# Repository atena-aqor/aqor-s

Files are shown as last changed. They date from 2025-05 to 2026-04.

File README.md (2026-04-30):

# Architecture du projet AQOR
## Présentation du projet
Le projet AQOR de mesure de la qualité de l'air et du bruit est organisé autour de capteurs fonctionnant sur batterie communiquant en protocole LORA avec une passerelle LORA-->Wifi permettant d'envoyer les mesures à un centre de collecte et de diffusion. Le projet comprend donc des aspects de fabircation du matériel et de développement du logiciel associé. Ces différents points sont abordés sur dépôt

### Architecture matérielle

 Le logiciel du projet AQOR a été développé en 3 parties distinctes qui reflètent l’architecture matérielle montrée ici:
 
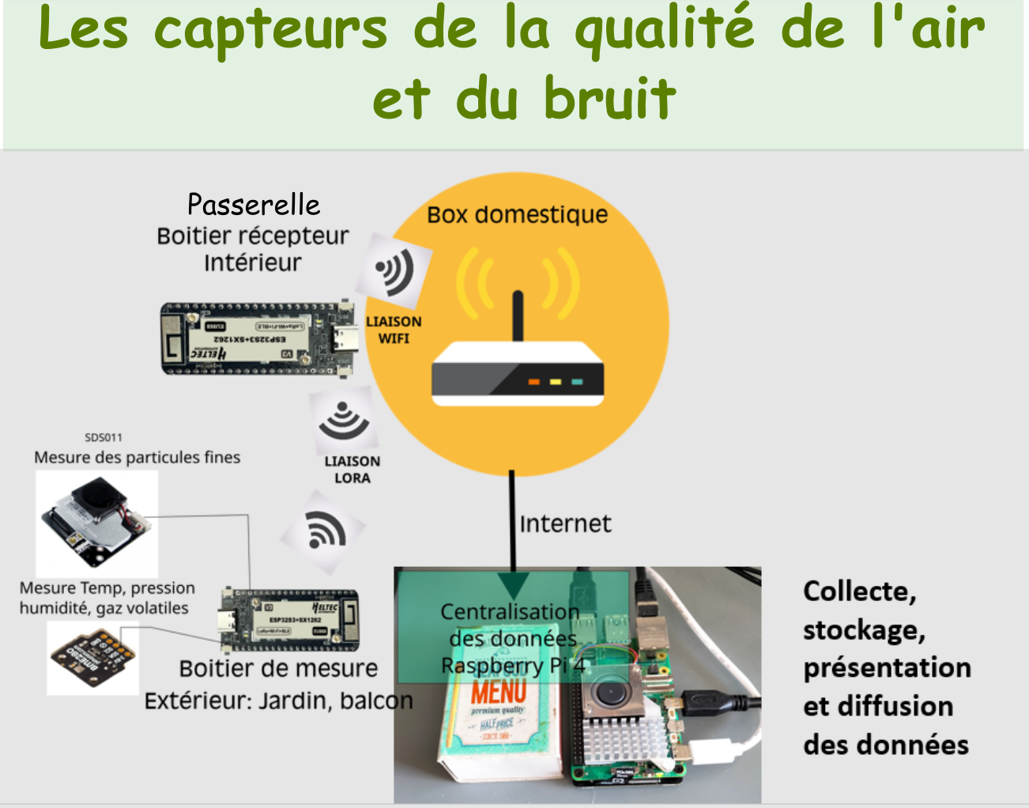
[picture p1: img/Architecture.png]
Architecture


#### Cartes électroniques pour le capteur 
L'électronique du capteur extérieur repose sur 3 cartes électronique dont les PCB réalisés avec KiCAD sont donnés dans les répertoires 
- pour la carte processeur: [Carte_Processeur](https://github.com/atena-aqor/aqor-s/tree/main/AQOR_Carte_Capteurs)
- pour la carte supportant les capteurs BME80 et INMP441 [Carte BME680/INMP441](https://github.com/atena-aqor/aqor-s/tree/main/AQOR_Carte_processeur)
Les cartes ont été développées avec le logiciel libre KiCAD en version 7.0

#### Boîtiers à imprimer
Les fichiers .STL pour l'impression 3D des boitiers sont donnés dans le répertoire: [Boitiers](https://github.com/atena-aqor/aqor-s/tree/main/AQOR%20STL)

### Architecture logicielle

Elle comprend:
- Un programme implanté dans le boîtier Emetteur qui fonctionne sur batterie
- Un programme implanté dans le boîtier Passerelle qui est connecté en WiFi à la box internet de l’hébergeur 
- Un logiciel Open Source de collecte et de diffusion des données implanté sur un micro-ordinateur Raspberry Pi5 fonctionnant sous linux UBUNTU. 

Les codes sources des programmes d'**émission** et de **passerelle** sont décrits dans les répertoires correspondants. Les fichiers Readme.md de chaque répertoire permettent de connaître le rôle de chaque fichier 

### Compilation des fichiers arduino 

Les fichiers proposés sont compilables sur la version de l'IDE Arduino 1.8.19 dont il faut choisir les préférences indiquées dans la figure suivante 

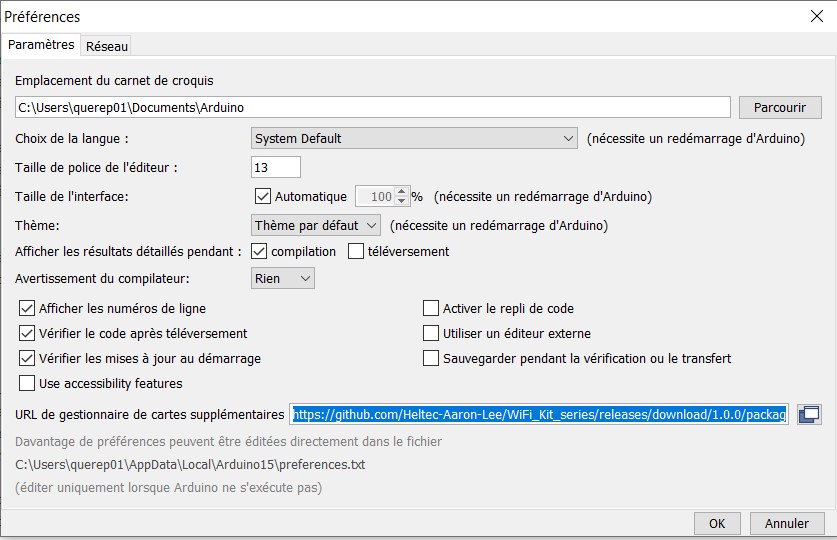
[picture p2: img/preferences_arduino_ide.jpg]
preferences_Arduino


le lien exact surligné en bleu  est [https://github.com/Heltec-Aaron-Lee/WiFi_Kit_series/releases/download/1.0.0/package_heltec_esp32_index.json](https://github.com/Heltec-Aaron-Lee/WiFi_Kit_series/releases/download/1.0.0/package_heltec_esp32_index.json)

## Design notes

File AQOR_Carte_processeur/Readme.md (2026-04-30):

# Fichiers de fabrication et de conception de la carte Processeurs
## Fichiers de fabrication
Dans ce répertoire on trouve les fichiers de fabrication qui peuvent être utilisés pour la réalisation des PCB de la carte processeur utilisée. Cette carte comporte le cablage du processeur et les connecteurs vers les différents éléments du capteur
L'aspect physique de la carte est donnée à la figure  ci-dessous 

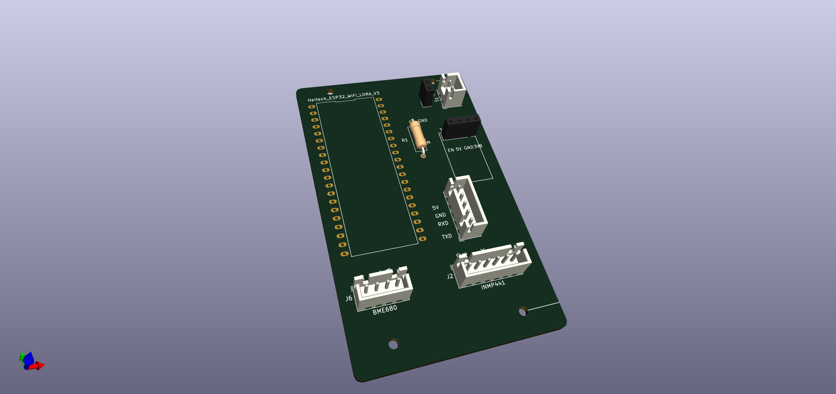
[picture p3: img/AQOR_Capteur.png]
CarteCapteur


et le schéma Kicad du PCB est donné ci-dessous

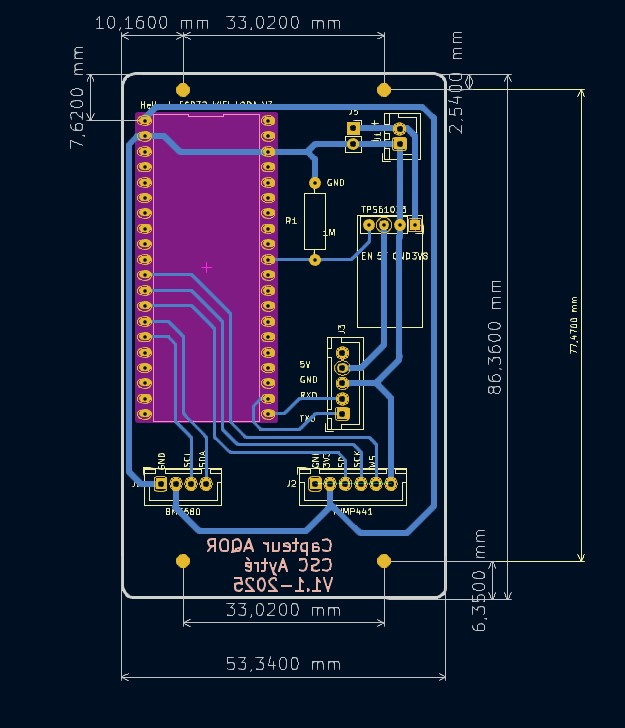
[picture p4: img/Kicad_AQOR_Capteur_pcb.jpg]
Kicad_PCB_carte_capteur


## Fichiers de conception 
La conception a été réalisée avec KICAD 7.0 [https://www.kicad.org/](https://www.kicad.org/)
Les fichiers de conception sont donnés dans le fichier [Kicad_AQOR_Capteur.zip](https://github.com/atena-aqor/aqor-s/blob/main/AQOR_Carte_processeur/Kicad_AQOR_Capteur.zip)

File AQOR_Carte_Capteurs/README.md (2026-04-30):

# Fichiers de fabrication et de conception de la carte Capteurs 
## Fichiers de fabrication
Dans ce répertoire on trouve les fichiers de fabrication qui peuvent être utilisés pour la réalisation des PCB de la carte processeur utilisée. Cette carte comporte le cablage du processeur et les connecteurs vers les différents éléments du capteur
L'aspect physique de la carte est donnée à la figure  ci-dessous 

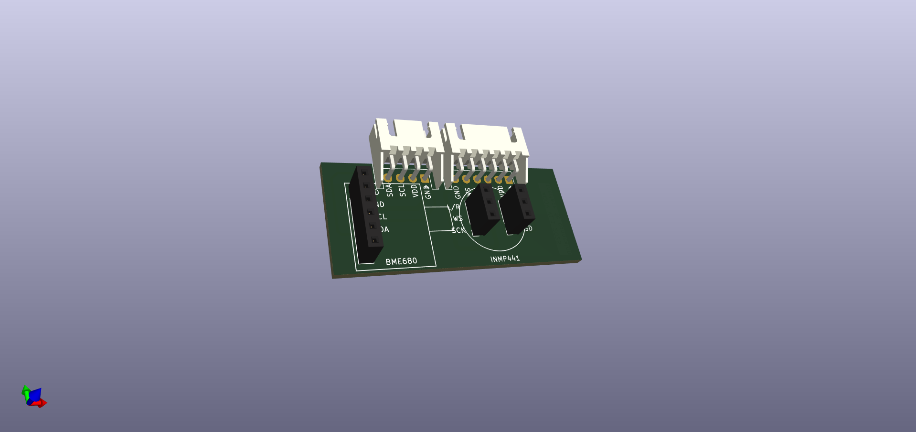
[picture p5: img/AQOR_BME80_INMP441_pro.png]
CarteCapteur


et le schéma Kicad du PCB est donné ci-dessous

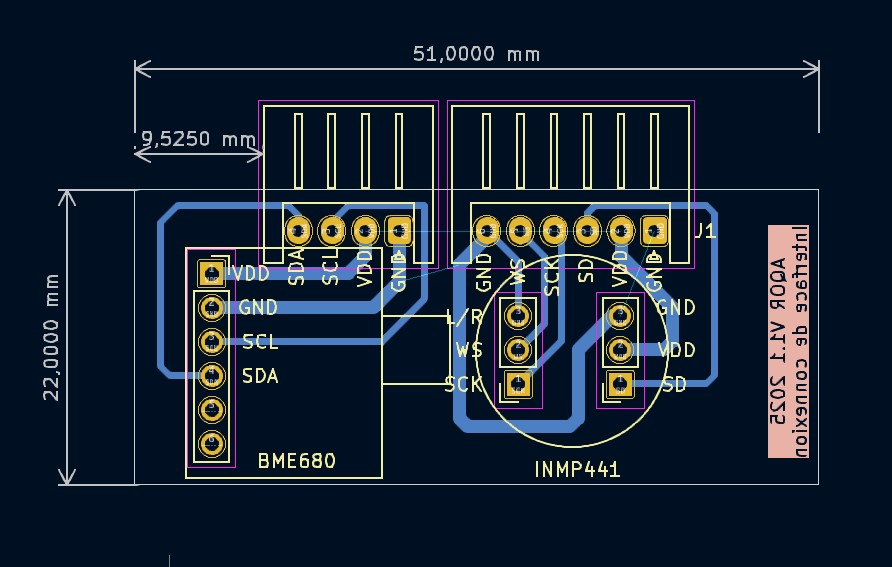
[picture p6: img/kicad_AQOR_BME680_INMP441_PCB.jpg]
Kicad_PCB_carte_capteur


## Fichiers de conception 
La conception a été réalisée avec KICAD 7.0 [https://www.kicad.org/](https://www.kicad.org/)
Les fichiers de conception sont donnés dans le fichier [Kicad_AQOR_BME80_INMP441_pro.zip](https://github.com/atena-aqor/aqor-s/blob/main/AQOR_Carte_Capteurs/Kicad_AQOR_BME80_INMP441_pro.zip)

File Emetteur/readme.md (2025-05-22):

# Documentation EmetteurAQOR

## Présentation du projet

EmetteurAQOR est un système IoT de surveillance de la qualité de l'air et de l'environnement qui :
- Mesure les particules fines (PM2.5 et PM10) avec un capteur SDS011
- Capture les données environnementales (température, humidité, pression, COV) avec un capteur BME680
- Enregistre les niveaux sonores avec un microphone INMP441
- Surveille le niveau de batterie
- Transmet toutes ces données via LoRa
- Optimise la consommation d'énergie avec des cycles de veille profonde

## Structure du code

Le projet est organisé en plusieurs fichiers pour améliorer la lisibilité et la maintenance :

```
EmetteurAQOR/
├── EmetteurAQOR.ino     # Programme principal
├── config.h             # Configuration globale et constantes
├── lora_manager.h       # Gestion des communications LoRa
├── power_manager.h      # Gestion de l'alimentation et du sommeil
├── SDS011Sensor.h       # Gestionnaire du capteur de particules fines
├── BME680Manager.h      # Gestionnaire du capteur environnemental
├── INMP441Manager.h     # Gestionnaire du microphone
└── BatteryMonitor.h     # Gestionnaire de batterie
```

## Fonctionnement général

Le système fonctionne en deux phases distinctes :

### Phase 1 : Mesure du niveau sonore (20 premiers cycles)
- Le système se réveille
- Mesure le niveau sonore
- Calcule et stocke les moyennes et maximums
- Retourne en sommeil profond pendant `TIME_TO_SLEEP` secondes
- Répète ce cycle 20 fois

### Phase 2 : Collecte et transmission complète des données
- Mesure les particules fines (PM2.5 et PM10) avec le SDS011
- Collecte les données environnementales avec le BME680 (température, humidité, pression, COV)
- Utilise les données sonores accumulées lors de la phase 1
- Vérifie le niveau de batterie
- Transmet toutes les données via LoRa
- Réinitialise le compteur de cycles
- Retourne en sommeil profond

## Format des données transmises

Les données sont transmises dans un format CSV avec les valeurs suivantes :

```
PM2.5, PM10, Température, Humidité, Pression, Gas Resistance, IAQ, IAQ Accuracy, dB Moyen, dB Max, Compteur dB>60, % Batterie, Tension Batterie
```

Exemple : `12.5,25.3,22.1,45.5,1013.2,12000.0,45.0,3.0,42.5,68.3,5,85,3.78`

## Configuration

### Paramètres principaux (config.h)

- `TIME_TO_SLEEP` : Durée du sommeil entre deux mesures (secondes)
- `TIME_TO_MEASURE_PM` : Durée entre deux mesures de particules (secondes)
- `SOUND_MEASUREMENT_CYCLES` : Nombre de cycles pour mesurer le son (défaut : 20)

### Configuration LoRa (config.h)

- `RF_FREQUENCY` : Fréquence radio (défaut : 868 MHz)
- `TX_OUTPUT_POWER` : Puissance de transmission (défaut : 18 dBm)
- `LORA_BANDWIDTH` : Bande passante (défaut : 125 kHz)
- `LORA_SPREADING_FACTOR` : Facteur d'étalement (défaut : SF7)

### Configuration des broches (config.h)

- `RX_PIN` et `TX_PIN` : Connexion série pour le SDS011 (défaut : 5 et 4)
- `POWER_PIN` : Broche pour alimenter le capteur SDS011 (défaut : 21)
- `Vext` : Broche pour l'alimentation externe (défaut : 43)

## Personnalisation

### Modifier la durée du cycle de veille
Pour changer l'intervalle entre les mesures, modifiez `TIME_TO_SLEEP` dans `config.h`.

### Modifier le nombre de cycles de mesure sonore
Pour ajuster combien de cycles sont consacrés aux mesures sonores, modifiez `SOUND_MEASUREMENT_CYCLES` dans `config.h`.

### Ajuster les paramètres LoRa
Si vous rencontrez des problèmes de transmission ou si vous souhaitez optimiser la portée/consommation d'énergie, modifiez les paramètres LoRa dans `config.h` :
- Augmentez `LORA_SPREADING_FACTOR` pour une meilleure portée (au détriment du débit)
- Modifiez `TX_OUTPUT_POWER` pour ajuster la puissance d'émission

### Calibration de la batterie
Vous pouvez calibrer la mesure de batterie dans la fonction `setup()` du fichier principal :

```cpp
battery.setMaxVoltage(3.9);      // Tension maximale
battery.setMinVoltage(3.3);      // Tension minimale
battery.setDividerRatio(2.745);  // Ajustement du diviseur de tension
```

## Dépannage

### Le système ne se réveille pas correctement
- Vérifiez que `gpio_deep_sleep_hold_dis()` est correctement appelé après le réveil
- Assurez-vous que les broches sont correctement configurées pour le sommeil profond

### Les données LoRa ne sont pas transmises
- Vérifiez que l'initialisation du module LoRa est correcte
- Confirmez que les paramètres LoRa correspondent à votre récepteur
- Assurez-vous que la fonction `Radio.IrqProcess()` est appelée

### Erreurs de lecture des capteurs
- Vérifiez les connexions physiques
- Assurez-vous que l'alimentation des capteurs est suffisante
- Consultez les messages d'erreur série pendant le débogage

## Extension du projet

Voici quelques idées pour étendre ce projet :

1. **Ajout de nouveaux capteurs** :
   - Capteur de CO2
   - Capteur de lumière
   - Détecteur de mouvement PIR

2. **Améliorations du logiciel** :
   - Mise en mémoire flash des données en cas d'échec de transmission
   - Mise à jour OTA (Over-The-Air)
   - Interface de configuration WiFi

3. **Optimisation énergétique** :
   - Alimentation solaire avec gestion de charge
   - Adaptation dynamique des cycles de mesure selon le niveau de batterie

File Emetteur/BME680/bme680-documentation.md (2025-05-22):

# Documentation de la classe BME680Manager

## Description
La classe `BME680Manager` est une classe héritée de `Bsec` qui permet de gérer le capteur environnemental BME680 de Bosch. Elle utilise le protocole I2C pour communiquer avec le capteur et fournit des fonctions pour la configuration, la lecture des données et la mise en veille du capteur.

## Caractéristiques
- Lecture des données de température, humidité, pression atmosphérique et résistance de gaz
- Calcul de l'indice de qualité de l'air (IAQ)
- Estimation des équivalents de CO2 et de COV
- Mode veille pour économiser l'énergie
- Sortie de données au format JSON

## Dépendances
- Arduino.h
- Wire.h
- bsec.h (bibliothèque BSEC de Bosch)
- ArduinoJson.h

## Configuration matérielle
- Microcontrôleur: Heltec WiFi Lora 32 Stick Lite
- Communication I2C:
  - SDA: GPIO41
  - SCL: GPIO42
- Adresse I2C par défaut: 0x76 (peut être 0x77 sur certains capteurs)

## API

### Constructeur
```cpp
BME680Manager()
```
Crée une instance de la classe BME680Manager.

### Méthodes publiques

#### begin()
```cpp
bool begin()
```
Initialise le capteur BME680 et configure les capteurs virtuels BSEC.

**Retour:**
- `true` si l'initialisation a réussi
- `false` en cas d'échec

**Exemple:**
```cpp
if (!bme680.begin()) {
    Serial.println("Échec de l'initialisation du capteur BME680");
}
```

#### sleep()
```cpp
void sleep()
```
Met le capteur en mode veille pour économiser l'énergie.

**Exemple:**
```cpp
bme680.sleep();
```

#### wakeUp()
```cpp
void wakeUp()
```
Réveille le capteur du mode veille et le réinitialise.

**Exemple:**
```cpp
bme680.wakeUp();
```

#### readData()
```cpp
bool readData()
```
Lit les données du capteur et met à jour les variables internes.

**Retour:**
- `true` si de nouvelles données ont été lues
- `false` si aucune nouvelle donnée n'est disponible

**Exemple:**
```cpp
if (bme680.readData()) {
    // Traitement des nouvelles données
}
```

#### getJsonData()
```cpp
String getJsonData()
```
Retourne les valeurs des capteurs au format JSON.

**Retour:**
Une chaîne de caractères contenant les données au format JSON

**Format JSON:**
```json
{
    "temperature": 25.1,
    "humidity": 45.2,
    "pressure": 1013.25,
    "gas_resistance": 12345.67,
    "iaq": 50.5,
    "iaq_accuracy": 3,
    "co2_equivalent": 500.0,
    "voc_equivalent": 1.2
}
```

**Exemple:**
```cpp
String json = bme680.getJsonData();
Serial.println(json);
```

## Variables internes

### Capteurs disponibles
- **temperature**: Température en °C
- **humidity**: Humidité relative en %
- **pressure**: Pression atmosphérique en hPa
- **gasResistance**: Résistance du capteur de gaz en Ohms
- **iaq**: Indice de qualité de l'air (0-500)
- **iaqAccuracy**: Précision de l'IAQ (0-3)
- **co2Equivalent**: Estimation de la concentration en CO2 en ppm
- **breathVocEquivalent**: Estimation des composés organiques volatils en ppm

## Exemple d'utilisation complet

```cpp
#include <Arduino.h>
#include "BME680Manager.h"

BME680Manager bme680;

void setup() {
    Serial.begin(115200);
    while (!Serial) delay(10);
    
    Serial.println("Initialisation du capteur BME680...");
    if (!bme680.begin()) {
        Serial.println("Échec de l'initialisation du capteur BME680");
        while (1) delay(10);
    }
}

void loop() {
    // Lecture des données du capteur
    if (bme680.readData()) {
        // Affichage des données au format JSON
        Serial.println(bme680.getJsonData());
    }
    
    delay(5000);  // Attendre 5 secondes entre les lectures
    
    // Exemple de mise en veille
    bme680.sleep();
    delay(10000);  // En veille pendant 10 secondes
    bme680.wakeUp();
    delay(1000);   // Attendre que le capteur se stabilise
}
```

## Notes importantes
1. La bibliothèque BSEC doit être installée. Elle n'est pas disponible dans le gestionnaire de bibliothèques standard d'Arduino et doit être téléchargée depuis le site de Bosch.
2. Le capteur BME680 nécessite un temps de préchauffage pour stabiliser ses mesures, en particulier pour l'IAQ. Une précision optimale est atteinte après plusieurs heures de fonctionnement.
3. L'IAQ est un indice qui va de 0 (air très propre) à 500 (air très pollué).
4. La précision de l'IAQ est indiquée par la valeur iaqAccuracy:
   - 0 : Initialisation
   - 1 : Instable
   - 2 : Calibration en cours
   - 3 : Calibré (précision maximale)

## Dépannage
- Si le capteur ne s'initialise pas, vérifiez l'adresse I2C (0x76 ou 0x77)
- Si les valeurs sont incorrectes, vérifiez les connexions I2C et assurez-vous que le capteur n'est pas perturbé par des sources de chaleur ou d'humidité externes
- La bibliothèque BSEC étant propriétaire, elle peut nécessiter des mises à jour régulières depuis le site de Bosch

## Limitations
- Le mode veille implémenté dans cette classe est basique. Pour des économies d'énergie plus avancées, consultez la documentation BSEC de Bosch
- La fonction de calibration automatique de l'IAQ nécessite un fonctionnement continu du capteur sur plusieurs jours pour atteindre une précision optimale

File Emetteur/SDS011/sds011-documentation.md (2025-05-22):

# Documentation de la classe SDS011Sensor

## Description
La classe `SDS011Sensor` est une interface pour le capteur de particules fines SDS011, destinée à être utilisée avec les microcontrôleurs ESP32, en particulier le Heltec Wireless Stick Lite (V3). Elle gère l'alimentation du capteur, la communication série et le traitement des données pour mesurer les concentrations de particules PM2.5 et PM10 dans l'air.

## Caractéristiques
- Contrôle de l'alimentation pour économiser l'énergie
- Communication série via UART
- Calcul des moyennes de mesures pour améliorer la précision
- Formatage des données en JSON avec catégorisation de la qualité de l'air

## Configuration matérielle
- **RX** : GPIO5 pour recevoir les données du capteur
- **TX** : GPIO4 pour envoyer des commandes au capteur
- **Alimentation** : GPIO21 pour contrôler l'alimentation du capteur

## Méthodes

### Constructeur
```cpp
SDS011Sensor(int rxPin, int txPin, int powerPin);
```
Initialise le capteur avec les broches définies.
- `rxPin` : Broche de réception des données (GPIO5 recommandé)
- `txPin` : Broche de transmission des données (GPIO4 recommandé)
- `powerPin` : Broche contrôlant l'alimentation du capteur (GPIO21 recommandé)

### begin()
```cpp
void begin();
```
Configure les broches et l'UART pour la communication. Éteint le capteur par défaut.

### powerOn()
```cpp
void powerOn();
```
Active l'alimentation du capteur en mettant la broche d'alimentation à l'état HAUT.

### powerOff()
```cpp
void powerOff();
```
Désactive l'alimentation du capteur en mettant la broche d'alimentation à l'état BAS.

### readSensor()
```cpp
bool readSensor(float& pm25, float& pm10);
```
Lit une mesure unique du capteur si des données sont disponibles.
- `pm25` : Variable où stocker la valeur PM2.5 (en µg/m³)
- `pm10` : Variable où stocker la valeur PM10 (en µg/m³)
- **Retourne** : `true` si une mesure a été lue avec succès, `false` sinon

### measure()
```cpp
bool measure(float& pm25, float& pm10, int warmupTime = 10000, int sampleTime = 5000);
```
Réalise un cycle complet de mesure avec allumage du capteur, préchauffage, mesures multiples et extinction.
- `pm25` : Variable où stocker la valeur moyenne PM2.5 (en µg/m³)
- `pm10` : Variable où stocker la valeur moyenne PM10 (en µg/m³)
- `warmupTime` : Temps de préchauffage en millisecondes (défaut : 10000)
- `sampleTime` : Temps d'échantillonnage en millisecondes (défaut : 5000)
- **Retourne** : `true` si des mesures ont été obtenues avec succès, `false` sinon

### getJSON()
```cpp
String getJSON(float pm25, float pm10);
```
Génère une chaîne au format JSON contenant les données de mesure.
- `pm25` : Valeur PM2.5 à inclure (en µg/m³)
- `pm10` : Valeur PM10 à inclure (en µg/m³)
- **Retourne** : Chaîne JSON formatée

## Exemple d'utilisation

```cpp
#include "SDS011Sensor.h"

// Configuration des broches
#define RX_PIN 5     // GPIO5 pour RXD
#define TX_PIN 4     // GPIO4 pour TXD
#define POWER_PIN 21 // GPIO21 pour alimenter le capteur

SDS011Sensor particleSensor(RX_PIN, TX_PIN, POWER_PIN);

void setup() {
    Serial.begin(115200);
    particleSensor.begin();
    Serial.println("Capteur SDS011 initialisé");
}

void loop() {
    float pm25, pm10;
    
    if (particleSensor.measure(pm25, pm10)) {
        String jsonData = particleSensor.getJSON(pm25, pm10);
        Serial.println(jsonData);
    } else {
        Serial.println("{\"error\":\"Échec de la mesure\"}");
    }
    
    delay(300000); // 5 minutes entre les mesures
}
```

## Format JSON

Le format JSON retourné par `getJSON()` contient les champs suivants :
- `pm25` : Concentration de particules PM2.5 en µg/m³
- `pm10` : Concentration de particules PM10 en µg/m³
- `timestamp` : Horodatage en millisecondes depuis le démarrage du microcontrôleur
- `pm25_category` : Catégorie de qualité de l'air pour PM2.5 (Très bon, Bon, Moyen, Médiocre, Mauvais)
- `pm10_category` : Catégorie de qualité de l'air pour PM10 (Très bon, Bon, Moyen, Médiocre, Mauvais)

Exemple de sortie JSON :
```json
{
  "pm25": 12.3,
  "pm10": 23.4,
  "timestamp": 3600000,
  "pm25_category": "Bon",
  "pm10_category": "Très bon"
}
```

## Notes techniques
- Le capteur nécessite un préchauffage pour des mesures précises (10 secondes par défaut)
- Pour économiser l'énergie et prolonger la durée de vie du capteur, il est éteint entre les mesures
- Les catégories de qualité de l'air sont basées sur les normes européennes

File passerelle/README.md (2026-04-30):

# Passerelle LoRa/WiFi – Heltec Wireless Stick Lite

## Vue d'ensemble

Ce projet transforme un **Heltec Wireless Stick Lite** (ESP32 + SX1262) en
passerelle entre un réseau de capteurs LoRa et la plateforme IoT
**ThingsBoard**, accessible via WiFi.

Au premier démarrage (ou après effacement de la configuration), le contrôleur
ouvre un portail web captif permettant de saisir les paramètres réseau. Une
fois configuré et redémarré, il passe en mode opérationnel : il écoute en
continu les paquets LoRa des capteurs et les retransmet vers ThingsBoard par
requête HTTP.

---

## Architecture des fichiers

```
heltec_gateway/
├── heltec_gateway.ino    # Point d'entrée : setup() / loop() + gestion bouton reset
├── config_portal.h       # Interface du portail captif
├── config_portal.cpp     # Implémentation : AP, DNS captif, serveur web, polling /status
├── lora_gateway.h        # Interface du mode opérationnel LoRa
├── lora_gateway.cpp      # Implémentation : init radio, réception, envoi HTTP
├── eeprom_utils.h        # Interface EEPROM
├── eeprom_utils.cpp      # Implémentation : lecture, écriture, effacement
└── README.md             # Cette documentation
```

---

## Logique de démarrage

```
Mise sous tension
      │
      ▼
Lecture EEPROM
(SSID, password, token)
      │
      ├─ Données présentes ──► Connexion WiFi (20 s max) ◄── bouton reset actif ici
      │                              │
      │                    ┌─────────┴──────────┐
      │                    │ Succès              │ Échec
      │                    ▼                    ▼
      │              Mode opérationnel    Portail captif
      │              (LoRa RX continu)    ◄── bouton reset actif ici
      │              ◄── bouton reset actif ici
      │
      └─ Données absentes ──► Portail captif
```

Le **bouton USR SW (GPIO0)** est surveillé à chaque étape, y compris pendant la
tentative de connexion WiFi. Un appui long de 3 secondes efface l'EEPROM et
relance le portail (voir section dédiée).

---

## Mode portail captif — configuration initiale

### Accès

1. Connectez votre smartphone ou PC au réseau Wi-Fi **`Heltec-Config`**
   (mot de passe : `12345678`).
2. Ouvrez un navigateur : toute URL redirige automatiquement vers la page de
   configuration grâce au DNS captif.

### Fonctionnalités de la page web

| Fonctionnalité | Description |
|---|---|
| Scan des réseaux disponibles | Liste automatique des SSID visibles, rafraîchissement toutes les 30 s |
| Sélection par clic | Un clic sur un réseau remplit le champ SSID instantanément |
| Afficher / masquer le mot de passe WiFi | Bouton 👁 à droite du champ, bascule entre `•••` et texte clair |
| Champ jeton capteur (Device Token) | Saisie du jeton d'authentification ThingsBoard |
| Afficher / masquer le jeton | Bouton 👁 identique sur le champ jeton |
| Confirmation de connexion en temps réel | La page affiche le statut de la tentative avant tout redémarrage |

### Procédure de saisie recommandée

1. Cliquer sur le réseau cible dans la liste — le champ SSID est rempli automatiquement.
2. Saisir le mot de passe WiFi, puis utiliser le bouton 👁 pour **vérifier
   visuellement** ce qui a été tapé avant de valider.
3. Saisir le jeton ThingsBoard, vérifier de même avec le bouton 👁.
4. Cliquer sur **Enregistrer & Connecter**.

### Mécanisme de confirmation de connexion avant redémarrage

L'un des problèmes classiques des portails captifs est de perdre la page web
au moment où le contrôleur bascule sur le réseau cible. Ce firmware contourne
ce problème de la façon suivante :

1. Le navigateur envoie `POST /save` avec SSID, mot de passe et jeton.
2. Le Heltec répond immédiatement `{"accepted":true}` **sans couper l'AP** :
   il passe en mode `WIFI_AP_STA` (AP et station simultanés).
3. La tentative de connexion au réseau cible est lancée en arrière-plan.
4. Le navigateur interroge l'endpoint `/status` toutes les 2 secondes
   (maximum 12 tentatives, soit ~24 secondes).
5. Selon le résultat :
   - **Succès** → `/status` retourne `{"state":"connected","ip":"…"}`. La page
     affiche l'adresse IP obtenue et annonce le redémarrage imminent. Les
     paramètres sont alors écrits en EEPROM. Le Heltec redémarre ~1,5 s plus tard.
   - **Échec** (délai dépassé ou mot de passe erroné) → `/status` retourne
     `{"state":"failed"}`. La page affiche un message d'erreur, le formulaire
     est réactivé, et **aucune donnée n'est écrite en EEPROM**. On peut
     corriger et réessayer sans redémarrer.

---

## ⚠️ Point d'attention — Commutation automatique de réseau WiFi

### Le problème

Les smartphones et certains PC portables implémentent une fonction de
**roaming automatique** (ou « connexion intelligente ») : si le signal du
réseau auquel ils sont connectés devient jugé insuffisant, l'appareil bascule
silencieusement vers un autre réseau connu offrant un meilleur signal — sans
avertissement et sans couper la session visible.

Pendant la saisie du mot de passe et du jeton sur le portail captif du Heltec,
cette commutation peut survenir à tout moment. Ses effets sont :

- La page web se fige ou affiche une erreur réseau.
- La saisie en cours est perdue.
- Le formulaire ne peut plus être soumis tant que l'appareil n'est pas
  reconnecté manuellement à `Heltec-Config`.

Ce problème est d'autant plus fréquent que le portail ne diffuse qu'en
**2,4 GHz à faible puissance**, alors que les réseaux domestiques ou de bureau
peuvent offrir un signal 5 GHz nettement plus fort à proximité.

### Solutions côté appareil (recommandé)

Avant d'ouvrir le portail de configuration, désactiver temporairement la
commutation automatique sur l'appareil utilisé :

**Android** : Paramètres → Wi-Fi → (nom du réseau `Heltec-Config`) → désactiver
« Passer automatiquement au réseau mobile » ou « Wi-Fi intelligent ».

**iOS / iPadOS** : Paramètres → Wi-Fi → (icône ⓘ à côté de `Heltec-Config`)
→ désactiver « Connexion automatique » et « Rejoindre automatiquement ».

**Windows 11** : Paramètres → Réseau et Internet → Wi-Fi → Gérer les réseaux
connus → supprimer les réseaux concurrents le temps de la configuration, ou
activer le mode avion sur les adaptateurs 5 GHz.

**macOS** : Préférences Système → Wi-Fi → décocher « Rejoindre
automatiquement » sur les autres réseaux présents dans la liste.

### Mesures implémentées dans le firmware

Du côté du Heltec, deux précautions sont prises pour limiter les effets de ce
problème :

- **`WiFi.setAutoReconnect(false)`** est appelé systématiquement avant toute
  tentative de connexion. Cela empêche l'ESP32 lui-même de basculer vers un
  autre réseau connu en mémoire.
- Le mode **`WIFI_AP_STA`** maintient l'AP actif pendant la tentative de
  connexion au réseau cible : si la commutation s'est produite et que
  l'utilisateur se reconnecte manuellement à `Heltec-Config`, la page `/status`
  reprend son polling et affiche le résultat final sans qu'il soit nécessaire
  de tout recommencer.

---

## Mode opérationnel — réception LoRa et envoi HTTP

### Paramètres radio (modifiables dans `lora_gateway.h`)

| Paramètre | Valeur par défaut |
|---|---|
| Fréquence | 868 MHz (plan de fréquences EU868) |
| Spreading Factor | SF7 |
| Bandwidth | 125 kHz |
| Coding Rate | 4/5 |
| Puissance TX | 20 dBm |
| Longueur de préambule | 8 symboles |
| CRC | activé |
| Réception continue | activée (`rxContinuous = true`) |

### Format du paquet LoRa

```
<DeviceToken>,<val1>,<val2>,…,<valN>
```

Le premier champ est le jeton du capteur. Il est comparé (`strcmp`) au jeton
stocké en EEPROM : tout paquet portant un jeton inconnu est ignoré
silencieusement. Les valeurs suivantes sont mappées dans l'ordre sur les clés
de télémétrie :

| Position | Clé JSON ThingsBoard |
|---|---|
| 1 | `pm25` |
| 2 | `pm10` |
| 3 | `temperature` |
| 4 | `humidite` |
| 5 | `pression` |
| 6 | `IAQ` |
| 7 | `eqCO2` |
| 8 | `eqCOV` |
| 9 | `dBSPL` |
| 10 | `BAT%` |
| 11 | `BATVolt` |

### Envoi HTTP vers ThingsBoard

```
POST http://aqor.fr:8080/api/v1/<DeviceToken>/telemetry
Content-Type: application/json

{"pm25":12.3 ,"pm10":18.0 ,"temperature":21.5 , …}
```

### Note sur la boucle de réception

`Radio.IrqProcess()` est appelé **sans aucun `delay()`** dans `loraLoop()`.
Le SDK Heltec traite les interruptions radio via un flag positionné par l'ISR
SPI et consulté par `IrqProcess()` : tout délai bloquant supérieur à quelques
millisecondes ferait manquer la fenêtre de déclenchement de la callback
`onRxDone`. Un heartbeat non-bloquant (point affiché toutes les 5 s via
`millis()`) permet de confirmer visuellement que la boucle tourne.

---

## Remise à zéro par le bouton USR SW (GPIO0)

### Objectif

Effacer la configuration stockée en EEPROM (SSID, mot de passe, jeton) sans
câble série ni reflashage du firmware. Cas d'usage typique : le réseau WiFi
cible a changé de nom ou de mot de passe et le contrôleur ne parvient plus à
s'y connecter.

### Procédure

1. **Maintenir appuyé** le bouton **USR SW** (marqué `USR` sur le PCB, GPIO0)
   pendant **plus de 3 secondes**.
2. Le moniteur série affiche un compte progressif (`0 s / 3 s`, `1 s / 3 s`,
   `2 s / 3 s`).
3. À 3 s : l'EEPROM est effacée, le contrôleur redémarre et ouvre
   automatiquement le portail de configuration.

Un appui bref (< 3 s) est ignoré pour éviter les effacements accidentels.

### Disponibilité du bouton

| Moment | Disponibilité |
|---|---|
| Pendant la tentative de connexion WiFi au démarrage | ✔ Vérifié à chaque demi-seconde |
| En mode portail captif | ✔ Vérifié à chaque itération de `loop()` |
| En mode opérationnel LoRa | ✔ Vérifié à chaque itération de `loop()` |

Le bouton est donc utilisable **à tout moment**, y compris pendant les 20
secondes d'attente de connexion au réseau enregistré — ce qui est le scénario
le plus courant en cas de changement de réseau.

### Détail technique

GPIO0 est configuré en entrée avec pull-up interne (`INPUT_PULLUP`). Le bouton
physique est câblé entre GPIO0 et GND : l'état actif est `LOW`. La fonction
`checkResetButton()` dans `heltec_gateway.ino` gère la détection et le
chronomètre de manière bloquante pendant la durée de l'appui (3 s au maximum),
puis reprend le cours normal si l'appui est relâché avant l'échéance.

---

## Persistance EEPROM

| Paramètre | Adresse de base | Longueur max |
|---|---|---|
| SSID | 0 | 99 caractères |
| Mot de passe WiFi | 100 | 99 caractères |
| Jeton capteur (Device Token) | 200 | 99 caractères |

Chaque champ est précédé d'un octet de longueur. La taille totale réservée est
**512 octets**. L'effacement via le bouton reset remet uniquement les octets de
longueur à zéro (adresses 0, 100 et 200), ce qui est suffisant pour que les
fonctions de lecture retournent une chaîne vide et déclenchent le portail au
prochain démarrage.

---

## Dépendances (bibliothèques Arduino)

| Bibliothèque | Rôle |
|---|---|
| `WiFi.h` | Connectivité WiFi ESP32 (modes STA, AP, AP+STA) |
| `WebServer.h` | Serveur HTTP embarqué du portail captif |
| `DNSServer.h` | DNS captif — redirige toute requête vers le portail |
| `EEPROM.h` | Stockage persistant des paramètres de configuration |
| `HTTPClient.h` | Envoi des télémétries vers ThingsBoard |
| `LoRaWan_APP.h` | Couche radio SX1262 — SDK officiel Heltec |

---

## Compilation

| Paramètre Arduino IDE | Valeur |
|---|---|
| Carte | `Heltec Wireless Stick Lite (V3)` |
| Package | Heltec ESP32 Series (gestionnaire de cartes Heltec) |
| Fréquence CPU | 240 MHz |
| Partition | Default |
| Port série (debug) | 115200 baud |

---

## Évolutions possibles

- Affichage de l'état (IP, RSSI LoRa, dernière trame reçue) sur l'écran OLED
  du Heltec, pour un diagnostic sans moniteur série.
- Mise à jour du firmware en OTA (Over-The-Air) via le portail captif, afin
  d'éviter tout branchement physique sur le terrain.
- Passage en HTTPS pour l'envoi des télémétries (ajout d'un certificat racine
  ThingsBoard dans le firmware).
- Gestion multi-capteurs : table de correspondance jeton → endpoint HTTP
  distinct par capteur.
- Sauvegarde horodatée des trames reçues en cas de perte de connexion WiFi
  (buffer circulaire en RAM ou sur flash SPI).

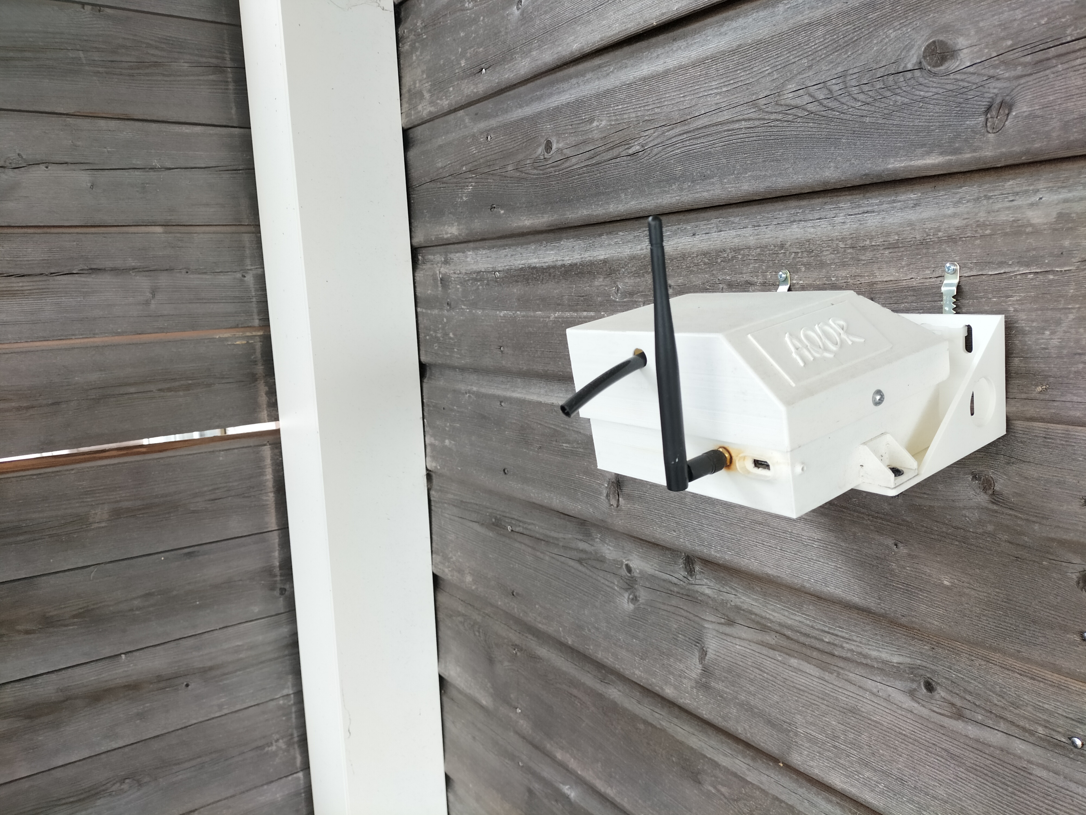
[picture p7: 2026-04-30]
img/support.jpg

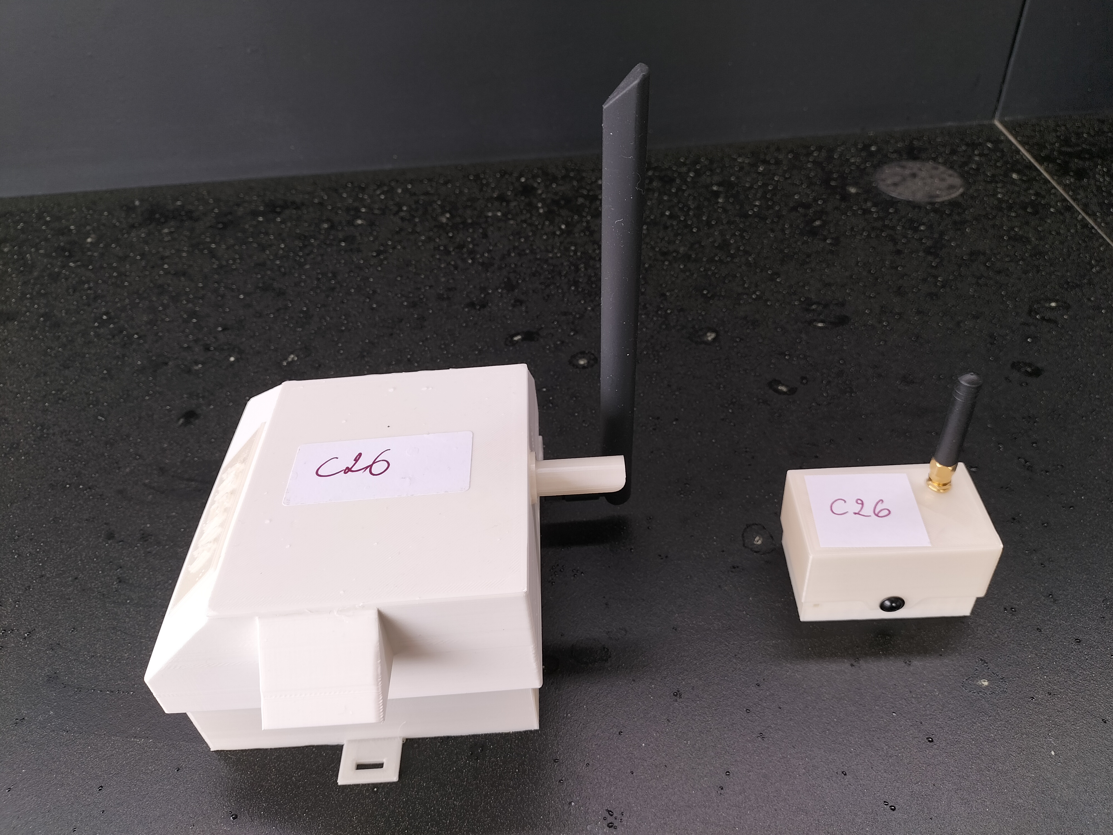
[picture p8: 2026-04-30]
img/Emetteur_Passerelle.jpg

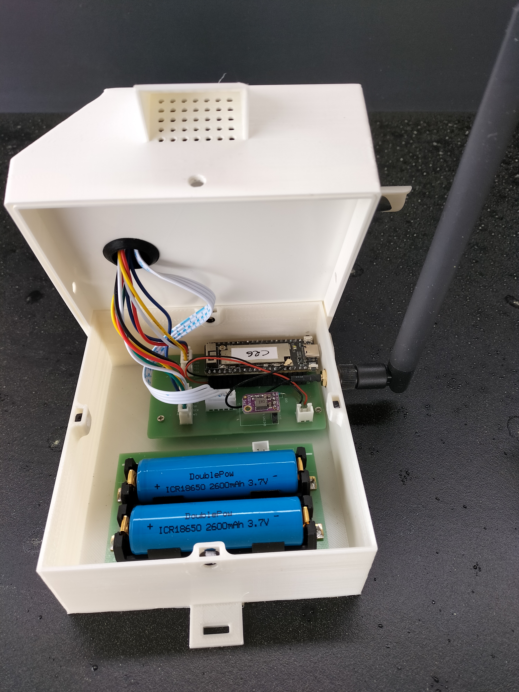
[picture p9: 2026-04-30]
img/emetteur.jpg

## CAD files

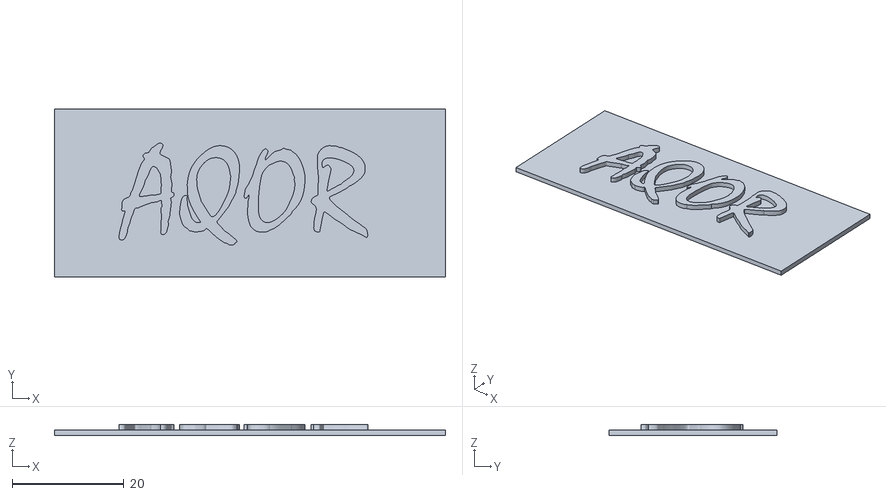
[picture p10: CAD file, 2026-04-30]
AQOR STL/AQOR Marquage Aqor-Body.stl
70.0 x 30.0 x 2.00

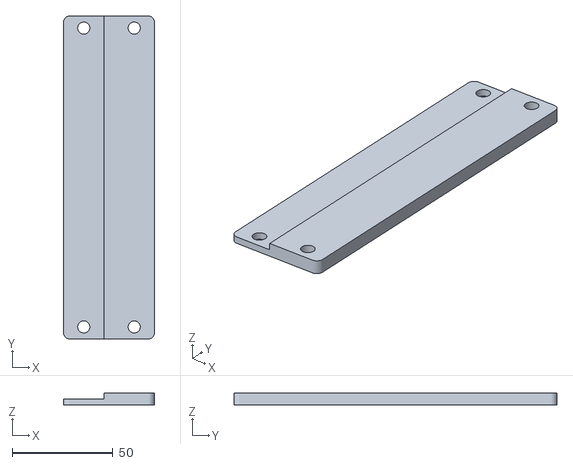
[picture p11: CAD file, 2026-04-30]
AQOR STL/AQOR Entretoise support-Body.stl
45.0 x 160.0 x 6.00

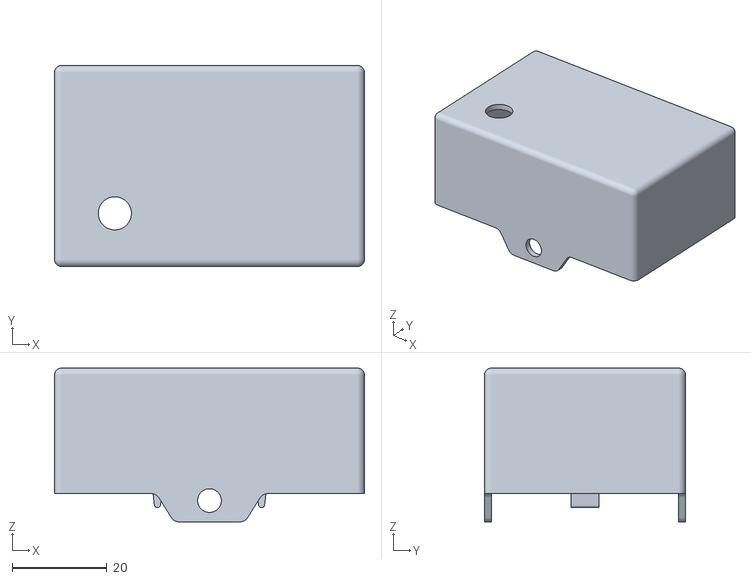
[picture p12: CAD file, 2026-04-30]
AQOR STL/AQOR Capot récepteur haut-Body.stl
65.5 x 42.5 x 32.5

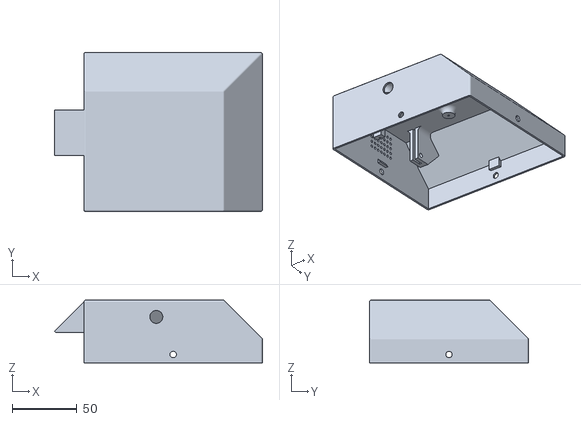
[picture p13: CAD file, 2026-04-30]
AQOR STL/AQOR Boitier haut appareils-Body.stl
160.6 x 123.0 x 48.5

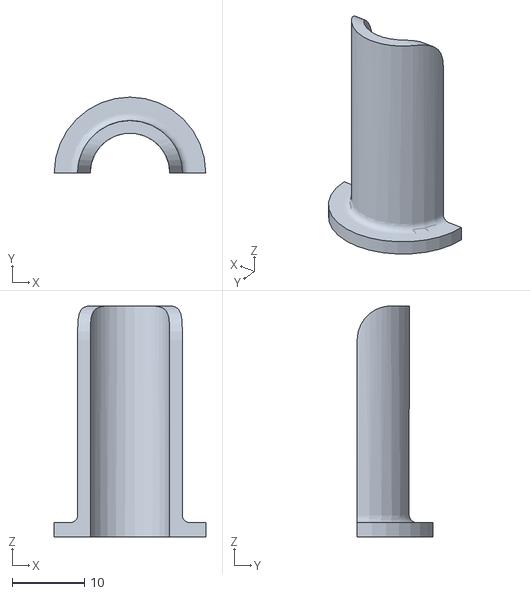
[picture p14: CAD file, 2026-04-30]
AQOR STL/Capot air-Body.stl
21.0 x 10.5 x 32.0

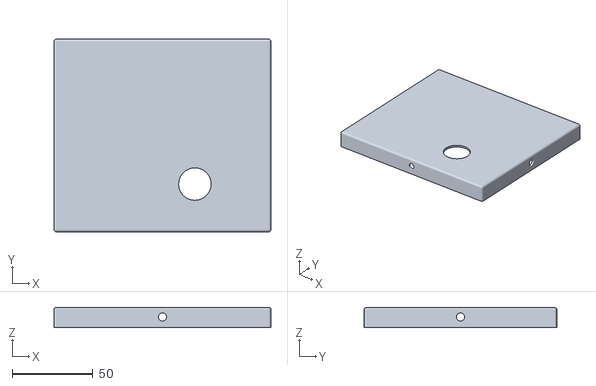
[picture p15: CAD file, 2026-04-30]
AQOR STL/AQOR Capot intermediaire-Body.stl
134.0 x 119.0 x 12.5

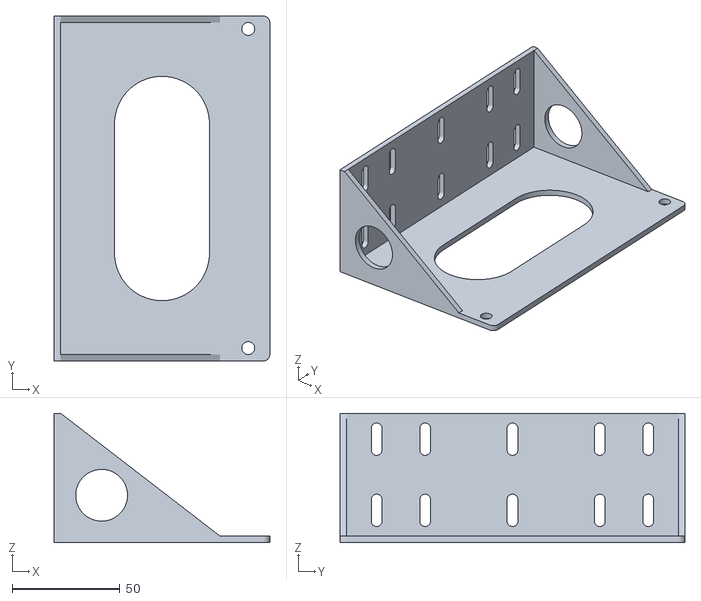
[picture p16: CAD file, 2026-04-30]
AQOR STL/AQOR Support boitier-Body.stl
100.0 x 160.0 x 60.0

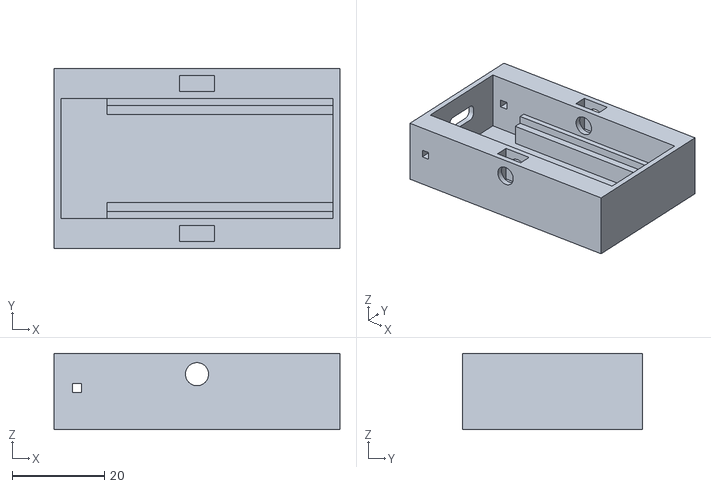
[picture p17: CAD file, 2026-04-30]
AQOR STL/AQOR Boitier recepteur bas-Body.stl
62.0 x 39.0 x 16.5

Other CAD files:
AQOR STL/AQOR Marquage Atena-Body.stl

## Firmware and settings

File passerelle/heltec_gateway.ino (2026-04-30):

/**
 * @file heltec_gateway.ino
 * @brief Passerelle LoRa/WiFi pour réseau de capteurs - Point d'entrée principal
 *
 * Ce fichier orchestre le démarrage :
 *  - Si des identifiants WiFi + jeton sont déjà stockés en EEPROM, on tente
 *    la connexion au réseau cible puis on passe en mode opérationnel LoRa.
 *  - Sinon (ou si la connexion échoue), on lance le portail captif de
 *    configuration WiFi (mode AP).
 *
 * Remise à zéro de l'EEPROM :
 *  - Appui long (> 3 s) sur le bouton USR SW (GPIO0) à n'importe quel moment
 *    → efface l'EEPROM et redémarre vers le portail de configuration.
 *
 * Architecture :
 *   heltec_gateway.ino   – setup() / loop() principal + gestion bouton
 *   config_portal.h/.cpp – portail captif (AP + serveur web + DNS)
 *   lora_gateway.h/.cpp  – réception LoRa et envoi HTTP vers ThingsBoard
 *   eeprom_utils.h/.cpp  – lecture / écriture / effacement EEPROM
 */

#include "config_portal.h"
#include "lora_gateway.h"
#include "eeprom_utils.h"

// ── Paramètres du point d'accès de configuration ────────────────────────────
const char* AP_SSID     = "Heltec-Config";
const char* AP_PASSWORD = "12345678";

// ── Bouton USR SW ────────────────────────────────────────────────────────────
constexpr uint8_t  BTN_PIN          = 0;     // GPIO0 – actif à l'état BAS
constexpr uint32_t BTN_LONG_PRESS_MS = 3000; // durée d'appui pour effacement

// ── Variables d'état global ──────────────────────────────────────────────────
bool configMode = false;   ///< true = portail actif, false = mode opérationnel

// ============================================================================
//  Gestion du bouton USR SW (appui long = reset EEPROM)
//
//  À appeler régulièrement : dans la boucle de connexion WiFi ET dans loop().
//  Retourne true si un appui long a été détecté (le reboot est alors lancé
//  directement depuis cette fonction).
// ============================================================================
static void checkResetButton() {
    // Le bouton est actif bas (pull-up interne)
    if (digitalRead(BTN_PIN) != LOW) return;   // pas appuyé

    // Appui détecté : on chronomètre
    uint32_t pressStart = millis();
    Serial.println("[BTN] Appui détecté – maintenir 3 s pour effacer l'EEPROM…");

    while (digitalRead(BTN_PIN) == LOW) {
        uint32_t held = millis() - pressStart;

        // Feedback visuel dans le moniteur série toutes les 500 ms
        if (held % 500 < 20) {
            Serial.printf("[BTN] %lu s / 3 s\n", held / 1000);
        }

        if (held >= BTN_LONG_PRESS_MS) {
            Serial.println("[BTN] *** Effacement EEPROM et redémarrage ***");
            eepromClear();
            delay(200);
            ESP.restart();
            // — jamais atteint —
        }
        delay(20);
    }

    Serial.println("[BTN] Appui trop court – ignoré.");
}

// ============================================================================
void setup() {
    Serial.begin(115200);
    Mcu.begin();

    // Configuration du bouton USR SW avec pull-up interne
    pinMode(BTN_PIN, INPUT_PULLUP);

    // Initialisation EEPROM et lecture des valeurs stockées
    eepromInit();
    String storedSSID     = eepromReadSSID();
    String storedPassword = eepromReadPassword();
    String storedToken    = eepromReadToken();

    Serial.println("=== Heltec LoRa/WiFi Gateway ===");
    Serial.println("SSID stocké   : " + storedSSID);
    Serial.println("Jeton stocké  : " + storedToken);
    Serial.println("(Appui long sur USR SW pour effacer la config)");

    // ── Tentative de connexion au réseau enregistré ──────────────────────────
    if (storedSSID.length() > 0 && storedPassword.length() > 0) {
        Serial.println("Connexion au réseau : " + storedSSID);

        WiFi.mode(WIFI_STA);
        WiFi.setAutoReconnect(false);
        WiFi.begin(storedSSID.c_str(), storedPassword.c_str());

        // Boucle de connexion : on vérifie le bouton à chaque itération
        // ce qui permet de déclencher le reset même pendant cette attente.
        int attempts = 0;
        while (WiFi.status() != WL_CONNECTED && attempts < 40) {
            checkResetButton();   // ← interception bouton pendant la connexion
            delay(500);
            Serial.print(".");
            attempts++;
        }
        Serial.println();

        if (WiFi.status() == WL_CONNECTED) {
            Serial.println("WiFi connecté ! IP : " + WiFi.localIP().toString());
            delay(300);   // stabilisation SPI avant init radio
            loraInit(storedToken);
            configMode = false;
            return;
        } else {
            Serial.println("Échec de la connexion WiFi – lancement du portail.");
        }
    } else {
        Serial.println("Aucune configuration stockée – lancement du portail.");
    }

    // ── Mode portail captif ──────────────────────────────────────────────────
    portalStart(AP_SSID, AP_PASSWORD);
    configMode = true;
}

// ============================================================================
void loop() {
    // Le bouton est vérifié en premier dans tous les modes
    checkResetButton();

    if (configMode) {
        portalLoop();

        if (portalShouldReboot()) {
            Serial.println("Redémarrage suite à la configuration...");
            delay(1500);
            ESP.restart();
        }
    } else {
        loraLoop();
    }
}

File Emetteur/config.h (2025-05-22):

/*
 * config.h - Fichier de configuration pour EmetteurAQOR
 * 
 * Ce fichier contient toutes les constantes et définitions
 * globales utilisées par le programme.
 */

#ifndef CONFIG_H
#define CONFIG_H

// Constantes de temporisation
#define TIME_TO_SLEEP 5            // Durée de sommeil de l'ESP32 (secondes)
#define TIME_TO_MEASURE_PM 20      // Durée entre deux mesures PM (secondes)
#define SOUND_MEASUREMENT_CYCLES 40 // Nombre de cycles pour mesurer le son

// Définition des broches pour le capteur SDS011
#define RX_PIN 5                   // GPIO5 pour RXD
#define TX_PIN 4                   // GPIO4 pour TXD
#define POWER_PIN 21               // GPIO21 pour alimenter le capteur

// Configuration LoRa
#define RF_FREQUENCY 868000000     // Hz
#define TX_OUTPUT_POWER 18         // dBm
#define LORA_BANDWIDTH 0           // 0: 125 kHz, 1: 250 kHz, 2: 500 kHz, 3: Reserved
#define LORA_SPREADING_FACTOR 7    // SF7..SF12
#define LORA_CODINGRATE 1          // 1: 4/5, 2: 4/6, 3: 4/7, 4: 4/8
#define LORA_PREAMBLE_LENGTH 8     // Même pour Tx et Rx
#define LORA_SYMBOL_TIMEOUT 0      // Symboles
#define LORA_FIX_LENGTH_PAYLOAD_ON false
#define LORA_IQ_INVERSION_ON false
#define RX_TIMEOUT_VALUE 1000
#define BUFFER_SIZE 128            // Taille du payload

// Autres définitions
#define Vext 43                    // Broche d'alimentation externe (peut varier selon la carte)

#endif // CONFIG_H

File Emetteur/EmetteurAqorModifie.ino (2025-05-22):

/*
 * EmetteurAQOR - Système de mesure de qualité d'air
 * 
 * Ce programme collecte des données environnementales (particules fines, température,
 * humidité, pression, COV, niveau sonore) et les transmet via LoRa.
 * Le système fonctionne en cycles de veille/réveil pour économiser l'énergie.
 */

#include "config.h"
#include "lora_manager.h"
#include "power_manager.h"
#include <SPI.h>

// Inclusion des gestionnaires de capteurs
#include "SDS011Sensor.h"
#include "BME680Manager.h"
#include "INMP441Manager.h"
#include "BatteryMonitor.h"

// Variables pour stocker les données mesurées entre les cycles de veille
RTC_DATA_ATTR int wake_count = 0;
RTC_DATA_ATTR float dBMoyen = 0;
RTC_DATA_ATTR float dBmax = 0;
RTC_DATA_ATTR int dBmaxCount = 0;

// Instanciation des objets pour les capteurs
SDS011Sensor particleSensor(RX_PIN, TX_PIN, POWER_PIN);
BME680Manager bme680;
INMP441Manager mic;
BatteryMonitor battery;

void setup() {
    Serial.begin(115200);
    Serial.print("Nombre d'endormissements: ");
    Serial.println(wake_count++);
   PowerOFF(POWER_PIN);
    delay(1000);
    
    // Phase 1: Mesure du niveau sonore pendant les premiers cycles
    if (wake_count < SOUND_MEASUREMENT_CYCLES) {
        measureSound();
        // Préparation pour le sommeil
        VextOFF();
        Radio.Sleep();
        SPI.end();
        gpio_hold_en((gpio_num_t)POWER_PIN);
        gpio_deep_sleep_hold_en();
        goToSleep(TIME_TO_SLEEP);
        return; // Sortie anticipée après la mesure de son
    }
    
    // Phase 2: Collecte et transmission des données complètes
    
    // Initialisation et mesure des particules fines
    // Réactivation de la broche Enable su TPS6203
    gpio_deep_sleep_hold_dis();
    gpio_hold_dis((gpio_num_t)POWER_PIN);
    
    particleSensor.begin();
    Serial.println("Capteur SDS011 initialisé");
    
    float pm25, pm10;
    if (!particleSensor.measure(pm25, pm10)) {
        Serial.println("{\"error\":\"Échec de la mesure de particules\"}");
    }
    
    // Initialisation et mesure BME680
    float sensorValues[8] = {0}; 
    if (!bme680.begin()) {
        Serial.println("Échec de l'initialisation du capteur BME680");
    } else {
        if (bme680.readData()) {
            bme680.getDataValues(sensorValues, true);
        }
        bme680.sleep();
    }
    
    // Mesure de la batterie
    battery.begin();
    battery.setMaxVoltage(3.9);
    battery.setMinVoltage(3.3);
    battery.setDividerRatio(2.745);
    battery.update();
    float batteryVoltage = battery.getVoltage();
    int batteryPercent = battery.getPercentage();
    
    // Transmission des données via LoRa
    initLoRa();
    
    char txpacket[BUFFER_SIZE];
    sprintf(txpacket, "%0.1f,%0.1f,%0.1f,%0.1f,%0.1f,%0.1f,%0.1f,%0.1f,%0.1f,%0.1f,%d,%d,%0.2f",
            pm25, pm10, sensorValues[0], sensorValues[1], sensorValues[2], sensorValues[4],
            sensorValues[6], sensorValues[7], dBMoyen, dBmax, dBmaxCount, batteryPercent,
            batteryVoltage);
    
    Serial.printf("\r\nEnvoi du paquet \"%s\" , longueur %d\r\n", txpacket, strlen(txpacket));
    sendLoRaPacket(txpacket);
    
    // Réinitialisation pour un nouveau cycle complet
    wake_count = 0;
    dBMoyen = 0;
    dBmax = 0;
    dBmaxCount = 0;
    prepareDeepSleep(POWER_PIN);
    goToSleep(TIME_TO_SLEEP);
}

void loop() {
    // Rien à faire dans la boucle, tout est géré dans setup() avec des cycles de veille
}

// Fonction pour mesurer le son
void measureSound() {
  float db;
    if (!mic.begin()) {
        Serial.println("Échec de l'initialisation du microphone INMP441");
        return;
    }
    
    Serial.println("INMP441 initialisé");
    //boucle pour stabiliser la mesure
    for (int i = 0; i< 10; i++){
      if (mic.readSound()) {
      db = mic.getDbValue();
      }
    }   
        //Serial.print("Niveau sonore");
        Serial.println(db);
        dBMoyen += db;
        dBMoyen /= 2;
        //Serial.print("Niveau sonore moyen");
        Serial.println(dBMoyen);
         
    }

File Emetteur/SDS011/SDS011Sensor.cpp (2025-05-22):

#include "SDS011Sensor.h"

// Constructeur avec la syntaxe correcte
SDS011Sensor::SDS011Sensor(int rxPin, int txPin, int powerPin) 
    : _sdsSerial(1), _rxPin(rxPin), _txPin(txPin), _powerPin(powerPin) {
}

void SDS011Sensor::begin() {
    _sdsSerial.begin(9600, SERIAL_8N1, _rxPin, _txPin);
    pinMode(_powerPin, OUTPUT);
    powerOff(); // Démarrer avec le capteur éteint
}

void SDS011Sensor::powerOn() {
    digitalWrite(_powerPin, HIGH);
}

void SDS011Sensor::powerOff() {
    digitalWrite(_powerPin, LOW);
}

bool SDS011Sensor::readSensor(float& pm25, float& pm10) {
    if (_sdsSerial.available() >= 10) {
        _sdsSerial.readBytes(_buffer, 10);
        
        // Vérifier l'en-tête et la fin de trame
        if (_buffer[0] == 0xAA && _buffer[1] == 0xC0 && _buffer[9] == 0xAB) {
            // Calculer PM2.5 et PM10
            pm25 = ((_buffer[3] * 256) + _buffer[2]) / 10.0;
            pm10 = ((_buffer[5] * 256) + _buffer[4]) / 10.0;
            return true;
        }
    }
    return false;
}

bool SDS011Sensor::measure(float& pm25, float& pm10, int warmupTime, int sampleTime) {
    bool readSuccess = false;
    
    // Allumer le capteur
    powerOn();
    
    // Attendre que le capteur se réchauffe
    delay(warmupTime);
    
    // Vider le buffer série
    while (_sdsSerial.available()) {
        _sdsSerial.read();
    }
    
    // Période de mesure
    unsigned long startTime = millis();
    float totalPM25 = 0;
    float totalPM10 = 0;
    int readCount = 0;
    
    while (millis() - startTime < sampleTime) {
        float tempPM25, tempPM10;
        if (readSensor(tempPM25, tempPM10)) {
            totalPM25 += tempPM25;
            totalPM10 += tempPM10;
            readCount++;
        }
        delay(100);
    }
    
    // Éteindre le capteur après la mesure
    powerOff();
    
    // Calculer la moyenne si des lectures ont été obtenues
    if (readCount > 0) {
        pm25 = totalPM25 / readCount;
        pm10 = totalPM10 / readCount;
        readSuccess = true;
    }
    
    return readSuccess;
}

String SDS011Sensor::getJSON(float pm25, float pm10) {
    // Créer une chaîne JSON avec les données du capteur
    String jsonString = "{";
    jsonString += "\"Sensor\": \"SDS011\" ,";
    jsonString += "\"pm25\":" + String(pm25, 1) + ","; // 1 décimale
    jsonString += "\"pm10\":" + String(pm10, 1) ;
    
    /*// Ajouter un timestamp (millisecondes depuis le démarrage)
    jsonString += "\"timestamp\":" + String(millis()) + ",";
    
    // Ajouter les catégories de qualité de l'air selon les normes européennes
    // PM2.5 catégories: 0-10 (Très bon), 10-20 (Bon), 20-25 (Moyen), 25-50 (Médiocre), 50+ (Mauvais)
    String pm25Category;
    if (pm25 <= 10) pm25Category = "\"Très bon\"";
    else if (pm25 <= 20) pm25Category = "\"Bon\"";
    else if (pm25 <= 25) pm25Category = "\"Moyen\"";
    else if (pm25 <= 50) pm25Category = "\"Médiocre\"";
    else pm25Category = "\"Mauvais\"";
    
    // PM10 catégories: 0-20 (Très bon), 20-40 (Bon), 40-50 (Moyen), 50-100 (Médiocre), 100+ (Mauvais)
    String pm10Category;
    if (pm10 <= 20) pm10Category = "\"Très bon\"";
    else if (pm10 <= 40) pm10Category = "\"Bon\"";
    else if (pm10 <= 50) pm10Category = "\"Moyen\"";
    else if (pm10 <= 100) pm10Category = "\"Médiocre\"";
    else pm10Category = "\"Mauvais\"";
    
    jsonString += "\"pm25_category\":" + pm25Category + ",";
    jsonString += "\"pm10_category\":" + pm10Category;*/
    
    jsonString += "}";
    return jsonString;
}

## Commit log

2025-05-22 V1.0
    Première version du programme arduino de pilotage des capteurs embarqués.
2026-04-29 Fix image reference in README for Arduino preferences
2026-04-30 Ajout des dossiers
    [AQOR_Capteur-B_Cu.gbl, AQOR_Capteur-B_Mask.gbs, AQOR_Capteur-B_Silkscreen.gbo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]
2026-04-30 Update README with fabrication and PCB details
    Added information about the fabrication files and PCB connections.
2026-04-30 Fix image reference in README.md
    Removed duplicate image reference for PCB in README.
2026-04-30 Revise README to include design files section
    Updated the README to reflect both manufacturing and design files for the sensor board.
2026-04-30 Add README for processor board fabrication and design
    Added detailed information about the manufacturing and design files for the processor board, including images and links.
2026-04-30 Update README with sensor electronics information
    Added details about sensor electronics and PCB links.
